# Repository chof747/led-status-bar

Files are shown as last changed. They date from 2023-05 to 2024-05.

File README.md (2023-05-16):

## Status bar with RGB Leds

This is a breakout board containing 5 WS2812B compatible RGB Leds that can be used to display some kind of status information or for other presentation stuff

It contains the following elements:

- 5 WS2812B compatible surface mount RGB leds
- MOSFETs acting as signal level shifters so it can be triggered by a 3V3 signal while the LEDs are powered by a higher voltage
- By-pass capacitors for each LED according to the data sheets
- A 4-pin header so that it can be connected to VDD (e.g. 5V) and VREF (e.g. 3v3), GND and a data line
  (1 - VDD, 2- Data, 3 - VREF, 4 - GND)
- It contains an outbound connector to daisy chain boards

## Revision History:

- **v1.0**: Initial version (filed for fabrication: 19.04.2023, assembled 14.5.2023)
- **v1.1**: Corrected revision including fixed version for level shifting and an outbound connector

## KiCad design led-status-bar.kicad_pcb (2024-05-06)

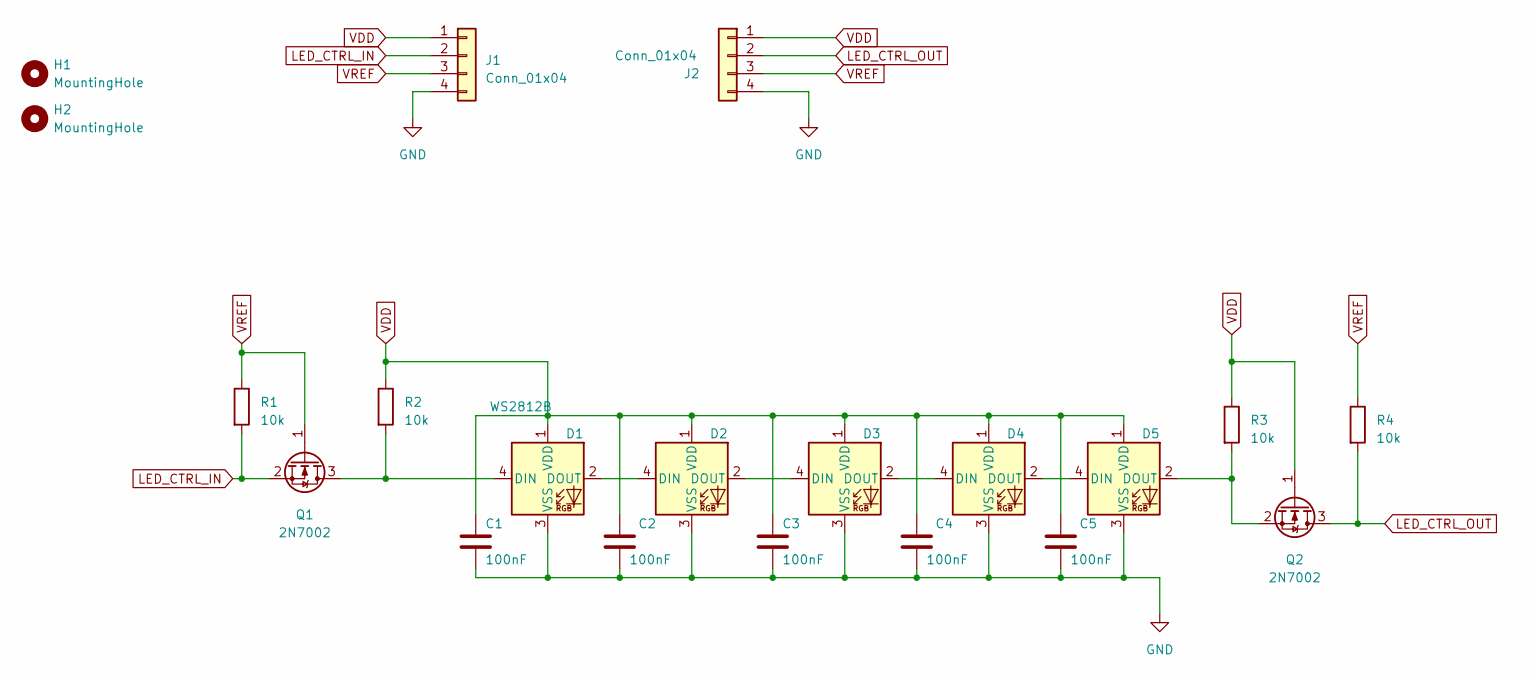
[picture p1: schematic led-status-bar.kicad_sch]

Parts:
C1, C2, C3, C4, C5: 100nF; C_0603_1608Metric_Pad1.08x0.95mm_HandSolder
D1, D2, D3, D4, D5: WS2812B; LED_WS2812B_PLCC4_5.0x5.0mm_P3.2mm
H1, H2: MountingHole; MountingHole_3.2mm_M3-smallBorder
J1: Conn_01x04; PinHeader_1x04_P2.54mm_Horizontal
J2: Conn_01x04; PinSocket_1x04_P2.54mm_Horizontal
Q1, Q2: 2N7002; SOT-23
R1, R2, R3, R4: 10k; R_0603_1608Metric_Pad0.98x0.95mm_HandSolder

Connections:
GND: C1.2, C2.2, C3.2, C4.2, C5.2, D1.3 (VSS), D2.3 (VSS), D3.3 (VSS), D4.3 (VSS), D5.3 (VSS), J1.4, J2.4
LED_CTRL_IN: J1.2, Q1.2 (S), R1.2
LED_CTRL_OUT: J2.2, Q2.3 (D), R4.2
unnamed: D1.4 (DIN), Q1.3 (D), R2.2
unnamed: D1.2 (DOUT), D2.4 (DIN)
unnamed: D2.2 (DOUT), D3.4 (DIN)
unnamed: D3.2 (DOUT), D4.4 (DIN)
unnamed: D4.2 (DOUT), D5.4 (DIN)
unnamed: D5.2 (DOUT), Q2.2 (S), R3.2
VDD: C1.1, C2.1, C3.1, C4.1, C5.1, D1.1 (VDD), D2.1 (VDD), D3.1 (VDD), D4.1 (VDD), D5.1 (VDD), J1.1, J2.1, Q2.1 (G), R2.1, R3.1
VREF: J1.3, J2.3, Q1.1 (G), R1.1, R4.1

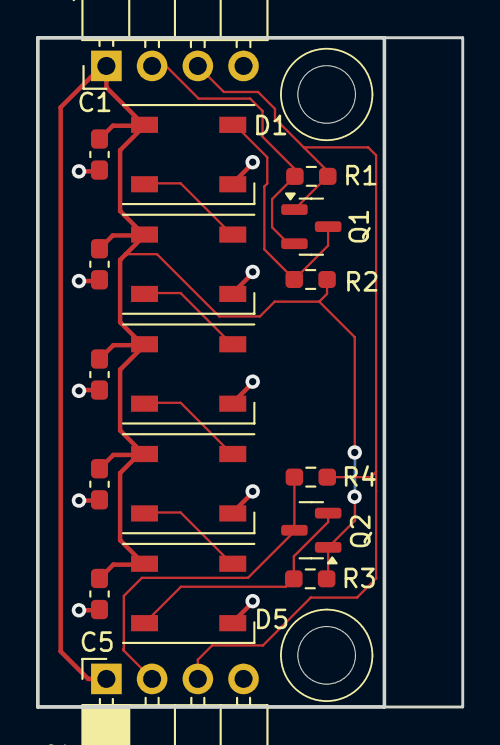
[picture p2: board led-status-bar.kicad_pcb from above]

Board: 2 copper layers, 23.6 x 37.2 mm, 20 parts (0 on the bottom side), 11 nets.

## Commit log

2023-04-20 Revision 1 commit
    - Added all required connections to the PCB
    - Fabrication revision 1
    - Added README with suitable information
    [led-status-bar.kicad_pcb, led-status-bar.kicad_sch]
2023-04-20 Added pinout to back of board
    [led-status-bar.kicad_pcb]
2023-04-27 Updated template for KiCAD 7
    [led-status-bar.kicad_pcb, led-status-bar.kicad_sch]
2023-05-16 Revision 1.1 - Correcting error with Level shift
    - Changed BJTs with N-Channel Mosfets
    - Added resistors accordingly
    - Added an outbound connector
    - Added Vref (3v3) to allow daisy chaining
    [led-status-bar.kicad_pcb, led-status-bar.kicad_sch]
2023-05-16 Corrected fab descriptions of connectors
    [led-status-bar.kicad_pcb, led-status-bar.kicad_sch]
2023-05-31 Final version for rev. 1.1
    [led-status-bar.kicad_pcb]
2023-09-19 Minor change: replaced pin headers with angled ones
    [led-status-bar.kicad_pcb, led-status-bar.kicad_sch]
2024-03-14 upgrade to KiCad 8.0
    [led-status-bar.kicad_pcb, led-status-bar.kicad_sch]
2024-05-06 Changes of uids - done by KiCad
    [led-status-bar.kicad_pcb]
